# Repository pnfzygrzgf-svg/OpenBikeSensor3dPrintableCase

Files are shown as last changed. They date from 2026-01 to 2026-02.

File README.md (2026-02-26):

# OpenBikeSensor Case

This repository contains the 3d-printable models for OpenBikeSensor enclosures.

[Project Website](https://openbikesensor.org) |
[Model selection](https://www.openbikesensor.org/device/) (German) |
[3D printing instructions](https://www.openbikesensor.org/docs/hardware/general/case/) (German)

> **Fork notice:** This repository is a **fork/clone** of the official
> [OpenBikeSensor case repository](https://github.com/openbikesensor/OpenBikeSensor3dPrintableCase)
> and includes additional variants.
>
> **New in this fork:**
> - **OpenBikeSensor Lite LiDAR case** (`src/LiteCaseLidar`) — enclosure for OBS Lite using a TF-Luna LiDAR sensor instead of ultrasonic
> - **18650 Battery Shield V3 cases** — enclosures for the battery shield, with variants for standard mount and LiDAR lid
> - **Extended seat post mount** (`SeatPostMount_long`) — longer seat post mount for more clearance
> - **Improved DisplayCase parametrization** — better OpenSCAD Customizer support

If you encounter any problems or have feature requests, please open an issue on
GitHub. If you need assistance related to the contents of this repository,
please ask in the [project forums](https://forum.openbikesensor.org).

## Cloning
If you want to build your own case using openscad instead of using the
readymade exports or if you want to start the customizer be aware
that you need to clone including git submodules:

```
git clone --recursive https://github.com/openbikesensor/OpenBikeSensor3DPrintableCase
# ... or if you forgot the --recursive argument, you can run this in the
# repository's directory later:
git submodule update --init --recursive
```

## About the files

We expect a recent version of OpenSCAD, for development we currently use OpenSCAD 2021.

This repository contains a lot of files for different options

* The `export/` folder contains the latest prebuilt `.stl` files for 3D printing.
  You can use those unless you want to make customizations. If you contribute
  changes to the models, you can refresh the models you changed using the
  ``make export-all`` command. If your ``openscad`` binary does not reside
  in ``/usr/bin/openscad`` you can specify its location by overriding the
  ``OPENSCAD`` variable like so (substitute your specific openscad path): ``make -j OPENSCAD=/Applications/OpenSCAD.app/Contents/MacOS/OpenSCAD``
* The `legacy/` folder contains old versions of the case, including lots of
  variants that were created but unmaintained. These were built with
  proprietary software packages and often available in their native format(s)
  and therefore mostly uneditable for most of the community. A lot of these
  files are also available in STEP format, and of course exported as STL for
  printing. We keep these files around for reference and convenience.
* The `lib/` folder contains common OpenSCAD files with library functions and
  modules, as well as exports of other objects that can be imported in the part
  files, e.g. to check dimensions.
* The `src/` folder contains OpenSCAD scripts for all parts. Not all parts are
  needed for printing a working enclosure. Please check the documentation
  (links on top) to assemble your custom list of parts for the variant you want
  to build.
* The `render/thumbnails/` folder contains rendered views of the parts. These images
  should be refreshed with changes to the parts using the `make thumbnails`
  command if you plan to submit your changes. They are used in this `README.md`.
* The `variables.scad` file contains all variables used in any of the parts.
  You can customize everything by editing this file, or passing new variable
  values on the OpenSCAD command line.

## The Standard Variant

There is a notion in the OpenBikeSensor community to label one combination of
parts and a certain version of the electronics the "Standard Model" (read about
it [here](https://www.openbikesensor.org/docs/hardware/general/models/)). This
is meant to get you started, without having to check for compatibility and
without cross referencing multiple parts of the documentation to build your own
version of the device.

> **Warning**
> We only keep the rail shapes constant between versions. When printing make sure that your ``MainCase`` and ``MainCaseLid`` come from the same release. The same is true for ``DisplayCase`` Top and Bottom. The Idea is that OpenBikeSensors can be mounted on a different bike with older version mounts, but the current version lid won't necessarily fit onto last years case.

To get a standard variant, print these parts:

```
MainCase/GpsAntennaLid
MainCase/MainCase
MainCase/UsbCover
MainCase/MainCaseLid
DisplayCase/DisplayCableStrainRelief (2x)
DisplayCase/DisplayCaseBottom
DisplayCase/DisplayCaseTop
Mounting/StandardMountAdapter
Mounting/SeatPostMount
Mounting/LockingPin
Mounting/HandlebarRail
```

## Compatibility

The parts are compatible with the OpenBikeSensor PCB Version `00.03.12`. Other
versions, both older and newer, might work, but are untested.

## Part list

This is a list of all available parts, and a description of what they are used for.

### Main case

The main case of the device enclosure. This will contain most of the
electronics. The core part are a `MainCase` and a `MainCaseLid`, which is
installed with five M3x8 bolts in the lid, matching the five threaded heatset
inserts in the body.

The PCB is installed into the main body with 3 heat-set inserts and M3x8 bolts.
One additional heat-set insert is required for the `GPSAntennaLid` (see below).
This totals 9 inserts to be placed after printing.

MainCase/MainCase

MainCase/MainCaseLid

#### GPS antenna lid

The `GpsAntennaLid` covers the part of the main enclosure with the GPS antenna.
It is held in place by only one M3x8 bolt and can be removed to reveal the
antenna, behind which there is an access hole for the Micro-USB receptable of
the ESP32 dev board -- very useful for debugging or developing the firmware.

MainCase/GpsAntennaLid

#### USB-C port cover

The `UsbCover` is small plug for the USB-C port on the bottom of the device,
which is used for charging the battery. This plug is held in place by 2 pairs
of 3x3x3mm neodymium magnets.

MainCase/UsbCover

### Display case

The display case consists of two halfs, `DisplayCaseTop` and
`DisplayCaseBottom`. The display case contains the I2C display and a push
button and is attached to the main device with a cable that exits through a
hole in the bottom part.

The bottom part contains 3 threaded heat-set inserts and a pocket for two
20x10x1.9mm neodymium magnets. The magnets hold the display in the rail on the
handlebar (see `HandlebarRail`).

DisplayCase/DisplayCaseTop

DisplayCase/DisplayCaseBottom

#### Display cable strain relief

*Print two copies of this.*

The `DisplayCableStrainRelief` holds the display cable firmly in place inside
the display case to prevent strain on the solder joints or crimped connectors
inside. The two halves are pushed into the hole at an angle one after the
other, and then screwed together with two M3x8 bolts and hex nuts.

DisplayCase/DisplayCableStrainRelief

### Mounting

#### Standard mount adapter

The `StandardMountAdapter` is screwed onto the main enclosure. It contains a
channel for the display cable to sit in, pressing it firmly against the outer
wall of the main case and relieving any strain from its connector inside.

This adapter is used to attach the device to the mount that is permanently
affixed to the bike. There may be different adapters in the future for
different attachment needs, but this one is the default.

Mounting/StandardMountAdapter

#### Seat post mount

The `SeatPostMount` gets attached to the seat post of the bicycle with zip ties.

*Hint: A piece of an old bicycle tube can prevent it from turning or shifting.*

This is a counterpart to the `StandardMountAdapter`, which can slide onto this
part's rail and be held in place with a `LockingPin`.

Mounting/SeatPostMount

#### Top tube mount

The `TopTubeMount` gets attached to the top tube of the bicycle frame, similar
to the seat post mount.

*Hint: A piece of an old bicycle tube can prevent it from turning or shifting.*

This is also compatible with the `StandardMountAdapter` and `LockingPin`. Make
sure to use a "Top Rider" variant main case (see below for details).

Mounting/TopTubeMount

#### Locking pin

Screw an M3x16 to M3x20 bolt through the `LockingPin` part, such that the
bolt's head sits on the long handle's side. Now you have a pin that you can
push into the hole in the `StandardMountAdapter` and turn 180 degrees, holding
the pin, and the device, in place.

Mounting/LockingPin

#### Handlebar rail

Attach the `HandlebarRail` to the handlebar of your bike with two zip ties or a single
hose clamp. Again, a piece from an old bicycle tube can prevent turning and shifting.

The large wall contains a pocket for two 20x10x1.9mm neodymium magnets, pushed
in one after the other. Make sure to consider their polarity to match those of
the display. The display can now slide onto this rail and is held in place by
the magnets.

Mounting/HandlebarRail

An alternative Handlebar rail can be mounted like most bike computers with a
rubber o ring;
Mounting/HandlebarRailOring

Often you find magnets where one magnet is strong enough for your display - you
can use a platic decoy to save on magnets in these cases
Mounting/DisplayMagnetDummy

#### Bike rack mount

The bike rack mount can be used to attach a "Top Rider" main case to a standard
bicycle rack. It consists of two parts, the `BikeRackMountSide` (which is
required twice) and `BikeRackMountCenter` or `BikeRackMountCenterLongitudinal`.

The side parts are mounted on the longitudinal rails of the rack, either above
or hanging below. They are connected with two rods (aluminium or wood) that
form cross beams, cut to sized depending on the width of the bike rack. In the
center of these rods sits the center piece, which has the attachment rail for
the sensor.

In a rotated version, the rods are aligned longitudinally, a difference center
piece (`BikeRackMountCenterLongitudinal`, third image) is used to rotate the
OBS correctly. Use this if you need your bike rack's longitudinal tubes for
attaching cargo, and you want to mount the OBS on the cross beams of the rack.

The rods can be affixed to the 3D printed parts by gluing them in place, once
they have been sized and fitted to your rack.

Mounting/BikeRackMountSide

Mounting/BikeRackMountCenter

Mounting/BikeRackMountCenterLongitudinal

#### Attachment cover

If you have a main case that has both attachment points (top rider and back
rider), you may want to cover the one of them that you are not using, such that
the screw holes and (optional) cable hole are not left open. The
`AttachmentCover` is a simple cover that fits the screw pattern.

Mounting/BikeRackMountSide

#### Back rider to top rider adapter

This adapter allows the use of a "back rider" main case on a "top rider" mount.
Print a second locking pin as well.

Mounting/BackRiderTopRiderAdapter

## Customization

There are tons of variables in the `variables.scad` file, mostly dimensions,
which can be adjusted to suit your needs. Some of these variables are however
not necessarily wise to be changed, as other dimensions might inadvertently
depend on them, or they might produce invalid results in certain ranges.

However, some options are meant to be changed to suit your specific needs. The
defaults get you most of the way, but certainly, some users will need a
different set of features, so here is a list of options you might want to
change:

### Print settings

Some options exist to control sizes and features that have been added just for
3D printing ease. Configure these to match your printing setup. The defaults
should work for most printers, but if you modify your settings greatly (e. g.
to print faster), you might also need to change these model parameters:

```
extrude_width
enable_easy_print
layer_height
default_clearance
```

### Top Rider vs. Back Rider

A "top rider" variant main case has an attachment port on the bottom (when
mounted), while a "back rider" has it on the front. The "traditional" OBS case
therefore is a back rider variant, as it used to always sit behind the seat
post, attached horizontally. However, many cyclists configure their bikes in a
way that there is not enough room for a whole OBS below the seat, so a
different way of attaching the OBS is needed.

Top riders can sit on the top tube, the luggage rack, or anywhere else where
there is support from below. Moving the attachment point on the main case makes
it simple to design compatible mounts with their rail on top, without a
complicated structure that "goes up and around" to provide a backwards-facing
rail.

A single case can have both top rider and back rider attachment ports. They
don't necessarily need to have an adapter attached, though it is recommended to
do so in order to fill the screw and cable holes.

To configure whether to generate top and/or back riders, set the following
variables. The `_cable` variables control whether the corresponding attachment
port (if it exists) has a hole for the cable or not.

```
MainCase_back_rider
MainCase_top_rider
MainCase_back_rider_cable
MainCase_top_rider_cable
```

The `Mounting/BackRiderTopRiderAdapter` is available for people who have a back
rider and would like to use a top rider mount. The opposite is not available.

### Dimensions

* General
  * `m3_screw_diameter_loose`: A hole for an M3 bolt has this diameter. The
    bolt is not meant to grab this hole, but slide into and out of it ("loose"
    fit). For (almost) each bolt, there is a corresponding threaded metal part
    (nut or insert), so increase this value if your bolts are hard to get where
    they need to go. Print `Calibration/ScrewHoles` to find a good value for
    your printer.
  * `m3_hex_nut_diameter`: The outer circle around a hex nut's hexagon has this
    diameter. This is **not** the same as the "wrench size" from [DIN
    934](https://www.fasteners.eu/standards/DIN/934/) (dimension `S`), but its
    nominal value is `2 / sqrt(3) * S`. For M3, this equals `6.35mm` nominally.
    Increase this for more clearance. Print `Calibration/HexNuts.stl` to find a
    good value for your printer.
* `SeatPostMount`
  * `SeatPostMount_angle`: Set to the angle that your seat post is away from
    the vertical in degrees (usually around 20). This ensures that the device
    will sit horizontally behind the seat post.
  * `SeatPostMount_diameter`: Set to the diameter of your seat post (in mm).
    The default for most bicycles today is 28.
  * `SeatPostMount_length`: Increase this to lengthen the mount,
    shifting the device further backwards on your bike. You might consider
    angular force, so don't set it too high, but this can help if your mount is
    hard to reach, or if the device disappears underneath your seat,
    potentially blocking GPS signal.
* `HandlebarRail`
  * `HandlebarRail_tube_radius`: The radius (half diameter) of your handlebar,
    in mm.

### Logo customization

The `Makefile` supports generating the case with different logos. For now, the
only parts that are customizable with logos are `MainCase/MainCase` and
`MainCase/MainCaseLid`. Please check the instructions in
[`logo/README.md`](./logo/README.md) for creating your own logo version.

## Legacy parts

The files of legacy versions are available in the ``.stl`` format for 3D
printing. But these are discretized versions of more universal 3D Geometry that
can be read and edited by CAD software.

This is a grown project and in the past contributions have been made with
different CAD Programs. Some parts were designed/modified in Autodesk inventor
(filenames `*.ipt`), some were designed in Fusion360 (filenames `*.f3d`), but
for most parts a step file (`*.stp, *.step`) is available which can be opened
by most CAD Programs. For your contributions in CAD software of your choice it
would be great if you could also follow the practice of submitting your changes
in both `.stl` for 3D-Printing and `.step` for later editing - and maybe the
native format of your CAD software on top.

OpenSCAD is a special case of course: Here submitting `.stl` (for now) and the
`.scad` file is sufficient. 

### Customizer webservice

To run the customizer webservice you run it from the dockerfile (and be sure
that you cloned the repo recursively before building the cointainer:

```
git submodule update --init --recursive
docker build . -t customizer
docker run --rm -p 8001:80 customizer 
```

Whereafter you should be able to access your customizer on your host on port 8001.

Alternatively you can launch the python module directly using uvicorn,
but that is only recommended for dev setups an d will be described
in the module readme.

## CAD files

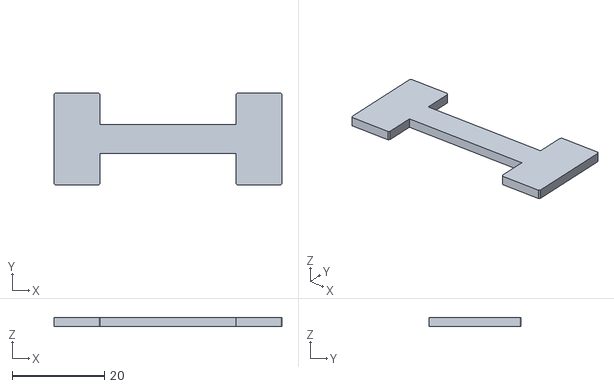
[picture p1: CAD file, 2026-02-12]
src/LiteCaseLidar/Spacer.stl
49.5 x 20.0 x 2.00

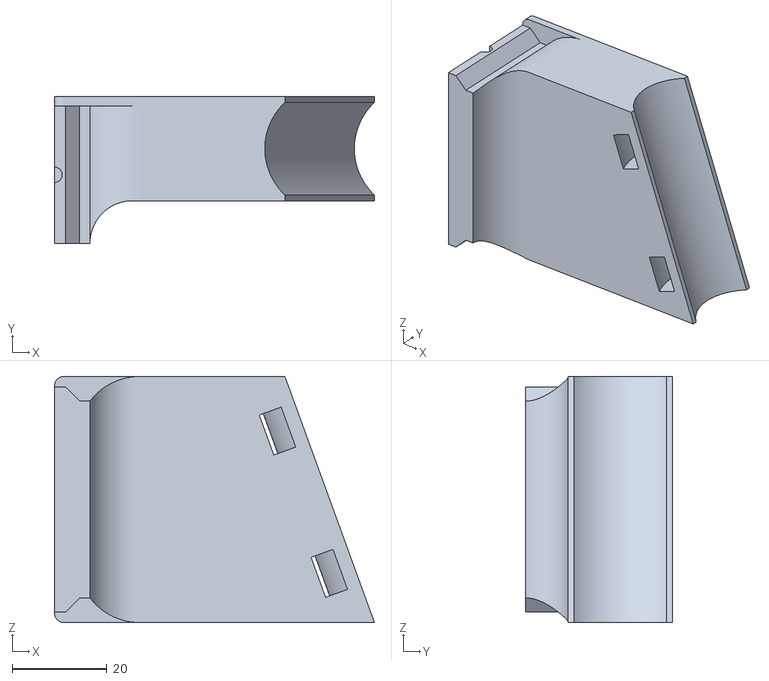
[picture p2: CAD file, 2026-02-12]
src/LiteCaseLidar/SeatPostMount_long.stl
67.6 x 31.0 x 52.0

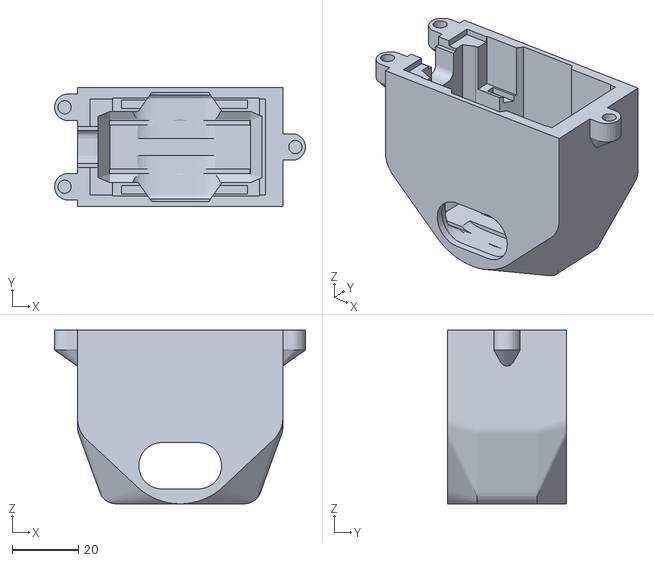
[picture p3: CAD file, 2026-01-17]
src/LiteCaseLidar/LiteCase_lidar_Schale.stl
75.8 x 36.0 x 52.4

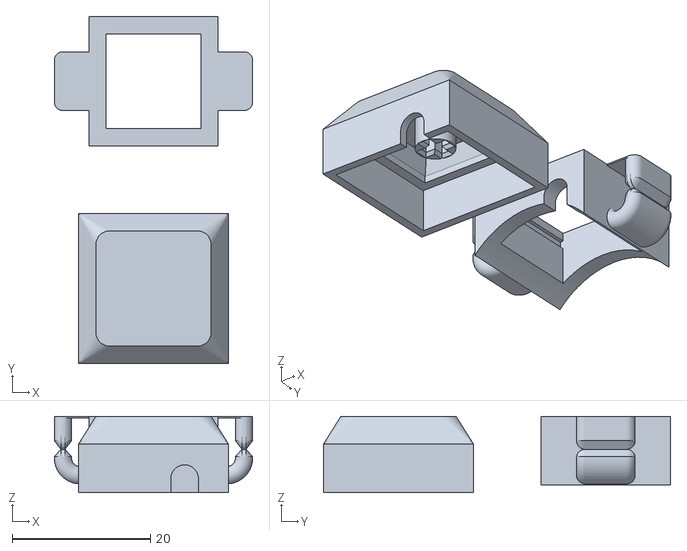
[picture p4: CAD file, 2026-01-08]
src/LiteCaseLidar/HandlebarButton.stl
28.7 x 50.2 x 11.0

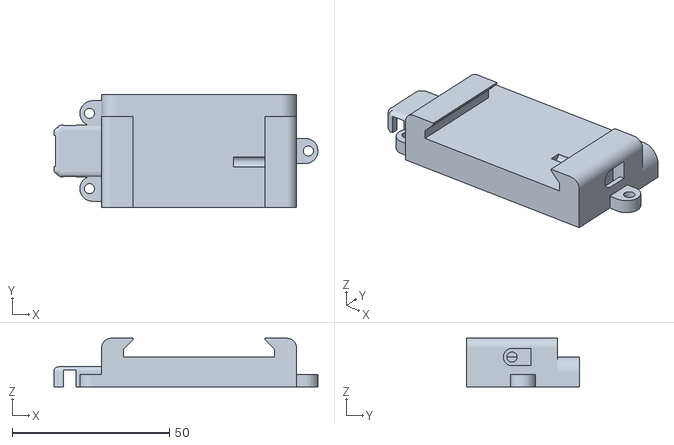
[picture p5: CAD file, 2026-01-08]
src/LiteCaseLidar/LiteCase_lidar_Deckel.stl
84.0 x 36.0 x 15.5

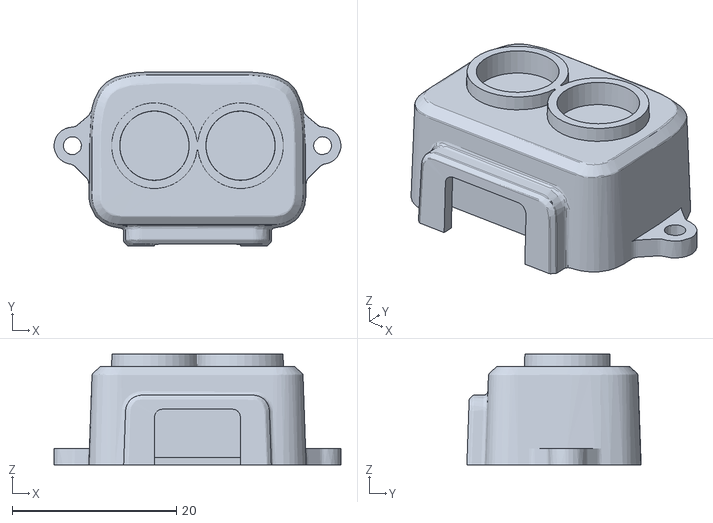
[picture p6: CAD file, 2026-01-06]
src/LiteCaseLidar/tfluna.stl
35.0 x 21.2 x 13.5

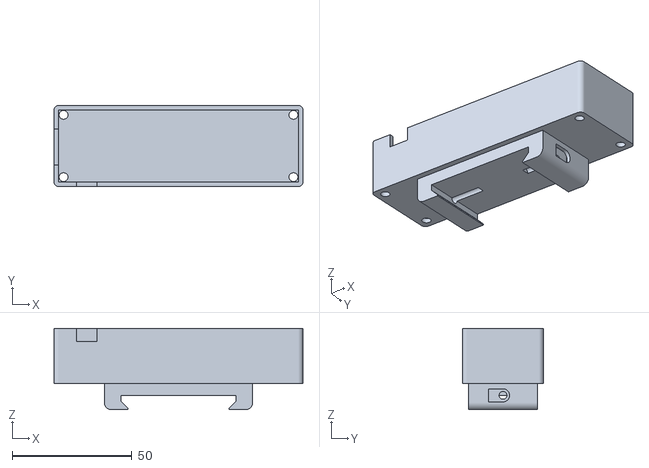
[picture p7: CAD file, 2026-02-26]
src/LiteCaseLidar/18650_BatteryShield_with_StandardMount.stl
104.0 x 34.0 x 34.0

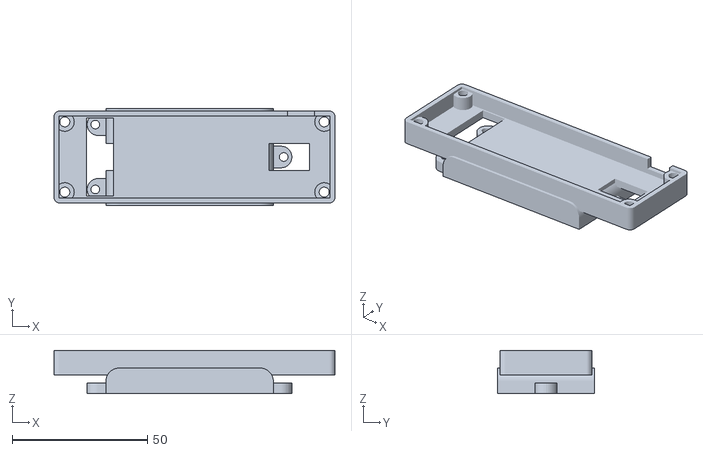
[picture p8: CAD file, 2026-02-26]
src/LiteCaseLidar/18650_BatteryShield_with_LiteCase_lidar_Deckel.stl
104.0 x 36.0 x 16.0

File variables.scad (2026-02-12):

// ==========================================================
//                      GLOBAL SETTINGS
// ==========================================================

// --------------
// Print settings
// --------------

// In some places we need to ensure a minimum wall thickness, so set this to
// your extrusion width. The default of 0.46mm is the PrusaSlicer default for a
// 0.4mm nozzle.
extrude_width = 0.46;

// Simplifies printing by adding smart bridges to remove need for supports.
enable_easy_print = true;
enable_text = true;
fix_svg = false;

// Used e.g. by easy print algorithms.
layer_height = 0.2;

// Size of the gap between two things that should fit into each other. This is
// gap size, so it applies to radii, not diameters.
default_clearance = 0.2;

// Set to false to generate nice previews and such, to true for printing output
// in proposed orientation.
orient_for_printing = false;

// ----------------------
// Model quality settings
// ----------------------

fast = $preview; // in fast mode, not all features are rendered
$fs = 0.2;
$fa = 1;
$fn = fast ? 24 : 120;
$pfn = $fn; // for polyRound
epsilon = 0.01; // infinitesimal thickness for slabs in hull - can be increased to see if offsets were done right.


// ==========================================================
//                    CUSTOMIZABLE OPTIONS
// ==========================================================

// A "back rider" is a case that has the attachment on front, riding e. g.
// behind the seat post. A "top rider" is a case that has an attachment on its
// bottom, sitting on top of a compatible mount, such as on the top tube or
// luggage rack. A single MainCase can be both back rider and top rider.
MainCase_back_rider = true;
MainCase_top_rider = true;
MainCase_back_rider_cable = true;
MainCase_top_rider_cable = true;

// General thickness of all walls of the main case and where applicable
wall_thickness = 2;

// -------------------------
// Dimensions of M3 hardware
// -------------------------

m3_screw_diameter_tight = 3.0; // screw should grab the plastic well
m3_screw_diameter_loose = 3.25; // screw should slide in nicely
m3_screw_head_depth = 3; // minimum depth for sinking the screw head
m3_screw_head_diameter = 6; // can have a little clearance
m3_hex_nut_diameter = 6.45; // outer circle, *not* wrench size (S), but `S*2/sqrt(3)`, plus clearance
m3_hex_nut_thickness = 2.5; // found different nut specifications, 2.5 is the maximum thickness I found named
m3_insert_hole_diameter = 4;
m3_insert_hole_depth = 6.0 ;
m3_insert_cavity_depth = 6.0 - 4.5;  // size of cavity on the bottom for displaced plastic
m3_insert_cavity_diameter = m3_insert_hole_diameter + 1;


// ==========================================================
//                     PART DIMENSIONS
// ==========================================================

// Warning: It may not be safe to modify all variables in this section, as they
// may not be tested for all desirable ranges and produce non-working results.
// Use at your own risk.

UsbCover_height = 9.7;
UsbCover_foot_height = 1.5;
UsbCover_width = 15.5;
UsbCover_depth = 6.5;
UsbCover_foot_length = 2.5;
UsbCover_r1 = 1.8; // the rounded corners with smaller radius
UsbCover_r2 = 2; // the rounded corners with bigger radius
UsbCover_magnet_size = 3.0; // decrease if magnets are too loose
UsbCover_magnet_clearance = 0.25; // increase if your printer needs more clearance for press fit
UsbCover_magnet_depth = 3.2;
UsbCover_magnet_spacing = 6.5; // center to center
UsbCover_indent_depth = 1.5;
UsbCover_indent_height = 4;
UsbCover_indent_width = 12;
UsbCover_wing_offset = 2.2;
UsbCover_wing_width = 2.6;
UsbCover_wing_length = 2.0;
UsbCover_clearance_correction = default_clearance; // printing a smaller-than-spec part for main cases that have not enough clearance themselves

MainCase_small_corner_radius = 5;
MainCase_switch_offset_x = 25;
MainCase_sensor_hole_diameter = 22.3; // 0.3 clearance
MainCase_sensor_hole_ledge = 1.0;

MainCase_pcb_offset = [1, UsbCover_depth + 0.5];
MainCase_pcb_holes = [[3.29+1.5, 23.75], [8.89+1.5, 49.3], [60.8+1.5, 41.63], [3.85+1.5, 61.65]];
// MainCase_pcb_dimensions = [64.64, 68.17, 2];

// found through experimentation
MainCase_usb_port_x_offset = 19.7+wall_thickness;
MainCase_usb_port_vertical_offset = 3.13; // center below the board bottom
MainCase_usb_port_housing_height = 14;
MainCase_usb_port_housing_width = 32;
MainCase_usb_port_housing_depth = MainCase_pcb_offset.y;
MainCase_usb_port_cover_clearance = default_clearance;

OBS_height = 72;
OBS_width = 113;
OBS_width_small = 88;
OBS_depth = 48;

MainCase_gps_antenna_y_offset = 32;
MainCase_gps_antenna_housing_hole_width = 26;
MainCase_gps_antenna_housing_hole_height = MainCase_gps_antenna_housing_hole_width;

MainCase_gps_antenna_lid_thickness = 2;
MainCase_gps_antenna_lid_offset = 3;
MainCase_gps_antenna_lid_tab_width = 10;
MainCase_gps_antenna_lid_tab_depth = 2;
MainCase_gps_antenna_lid_tab_height = 1;

MainCase_gps_antenna_height = 9;
MainCase_gps_antenna_housing_depth = MainCase_gps_antenna_height+MainCase_gps_antenna_lid_thickness;
MainCase_gps_antenna_housing_top_width = MainCase_gps_antenna_housing_hole_width-1;
MainCase_gps_antenna_housing_top_height = MainCase_gps_antenna_housing_hole_height+12;
MainCase_gps_antenna_housing_top_radius = 2;
MainCase_gps_antenna_housing_bottom_offset = 2;
MainCase_gps_antenna_housing_bottom_width = MainCase_gps_antenna_housing_top_width + 2 * MainCase_gps_antenna_height;
MainCase_gps_antenna_housing_bottom_height = MainCase_gps_antenna_housing_top_height + 2 * MainCase_gps_antenna_height - MainCase_gps_antenna_housing_bottom_offset;
MainCase_gps_antenna_housing_bottom_radius = MainCase_gps_antenna_housing_top_radius + MainCase_gps_antenna_housing_depth;
MainCase_gps_antenna_housing_screw_offset = 3;
MainCase_gps_antenna_housing_cable_hole_diameter = 6;

MainCase_micro_usb_offset = 30 + MainCase_pcb_offset.y + wall_thickness;
MainCase_micro_usb_width = 16;
MainCase_micro_usb_height = 14;
MainCase_micro_usb_chamfer = 4;

frontside_angle = atan((OBS_width - OBS_width_small) / OBS_height);

MainCaseLid_rim_clearance = 0.3;
MainCaseLid_rim_thickness = 3.0;
MainCaseLid_rim_width = 1;
MainCaseLid_rim_radius = 12;
MainCaseLid_thickness = 2.1;

MainCaseLid_hole4_offset_x = 35;
MainCaseLid_hole_offset = 3.5; // distance from inner wall
MainCaseLid_hole_positions = [
  [MainCaseLid_hole_offset+wall_thickness, MainCaseLid_hole_offset+wall_thickness],
  [OBS_height-MainCaseLid_hole_offset-wall_thickness, MainCaseLid_hole_offset+wall_thickness],
  [MainCaseLid_hole_offset+wall_thickness, OBS_width_small-MainCaseLid_hole_offset-wall_thickness-5],
  [OBS_height-MainCaseLid_hole_offset-wall_thickness, OBS_width_small-MainCaseLid_hole_offset-wall_thickness-5],
  [OBS_height-MainCaseLid_hole4_offset_x+4.5*cos(frontside_angle), OBS_width-tan(frontside_angle)*MainCaseLid_hole4_offset_x-3.5],
];

MainCaseLid_battery_holder_lift = 1.5;
MainCaseLid_battery_holder_inner_radius = 8;
MainCaseLid_battery_holder_inner_width = 18.3;
MainCaseLid_battery_holder_height = 11.5;
MainCaseLid_battery_holder_length = 37.6;

MainCaseLid_battery_holder_channel_depth = 2;
MainCaseLid_battery_holder_channel_radius = 5;
MainCaseLid_battery_holder_channel_extra_length = 5;
MainCaseLid_battery_holder_channel_width = 5;
MainCaseLid_battery_holder_channel_spacing = 17.6 + 5;

MountRail_base_width = 48;
MountRail_base_height = 2.5;
MountRail_chamfer_height = 3;
MountRail_plate_width = MountRail_base_width - 2 * MountRail_chamfer_height;
MountRail_plate_distance = 2;
MountRail_total_height = MountRail_base_height + MountRail_chamfer_height + MountRail_plate_distance;
MountRail_clearance = 0.2;
MountRail_width = 29.0;
MountRail_pin_length = 15;

SeatPostMount_width = 22; // [18:25]
SeatPostMount_angle = 20; // [0:35]
SeatPostMount_diameter = 28; // [18:36]
SeatPostMount_stop_plate_thickness = 2; // [1:0.1:3]
SeatPostMount_stop_plate_width = MountRail_base_width  + 4;
SeatPostMount_length = 20; // [15:100]
SeatPostMount_long_length = 60; // 
SeatPostMount_channel_depth = 4; // [1:20]

// TODO: decide on a namespace, at least `*_holes_dx/dy` are global
MountAttachment_depth = 4;
MountAttachment_height = 47;
MountAttachment_width = 27;
MountAttachment_holes_x_offset = -0.5;
MountAttachment_holes_dx = 15;
MountAttachment_holes_dy = 33;

DisplayCase_outer_radius = 5;
DisplayCase_outer_width = 30;
DisplayCase_outer_large_radius = 12;
DisplayCase_magnet_length = 20;
DisplayCase_magnet_thickness = 2;
DisplayCase_magnet_housing_width = 2*DisplayCase_magnet_thickness+default_clearance+2*extrude_width;
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

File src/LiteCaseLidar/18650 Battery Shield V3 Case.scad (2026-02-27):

// SPDX-License-Identifier: LGPL-3.0-or-later
// SPDX-FileCopyrightText: OpenBikeSensor contributors

//18650 Battery Shield V3 Case

// Welches Teil soll gerendert werden?
part = "both"; // Optionen: "top", "bottom", "both"

$fn=50;

// Radius für Kantenrundung
kantenradius = 2;

// PETG Drucktoleranz
toleranz = 0.1;

// V3 Dimensionen
length = 100;
width = 30;
holelength = 2;
holewidth = 2;

// Abstand zwischen den Teilen wenn beide angezeigt werden
spacing = 10;

if (part == "top" || part == "both") {
    topcase();
}

if (part == "bottom") {
    bottomcase();
}

if (part == "both") {
    translate([0, width + spacing, 0])
        bottomcase();
}

module topcase() {
    difference() {
        
        minkowski() {
            translate([-2 + kantenradius, -2 + kantenradius, -2]) 
                cube([length + 4 - 2*kantenradius, width + 4 - 2*kantenradius, 23 - kantenradius]);
            cylinder(r=kantenradius, h=kantenradius);
        }
        
        translate([-toleranz, -toleranz, 0])
            cube([length + 2*toleranz, width + 2*toleranz, 24]);
        
        translate([5.5 - toleranz, 2 - toleranz, 0])
            cube([length - 10.5 + 2*toleranz, width - 4 + 2*toleranz, 26]);
        
        // USB-Port V3
        translate([-4, 7, 13]) cube([10, 15, 8]);
        
        // Power Button
        translate([7.5, -2, 15.5]) cube([8.5, 5, 5.5]);
        
        // Nur Schaftbohrungen, Kopf liegt auf
        translate([holelength, holewidth, -4])               cylinder(30, 3.5/2 + toleranz, 3.5/2 + toleranz);
        translate([holelength, width-holewidth, -4])         cylinder(30, 3.5/2 + toleranz, 3.5/2 + toleranz);
        translate([length-holelength, holewidth, -4])        cylinder(30, 3.5/2 + toleranz, 3.5/2 + toleranz);
        translate([length-holelength, width-holewidth, -4])  cylinder(30, 3.5/2 + toleranz, 3.5/2 + toleranz);
    }
}

module bottomcase() {
    difference() {
        union() {
            difference() {
                // Abgerundeter Aussenkörper – Boden 3mm (z=-3)
                minkowski() {
                    translate([-2 + kantenradius, -2 + kantenradius, -3]) 
                        cube([length + 4 - 2*kantenradius, width + 4 - 2*kantenradius, 9 - kantenradius]);
                    cylinder(r=kantenradius, h=kantenradius);
                }
                
                // Innenraum
                translate([-toleranz, -toleranz, 0])
                    cube([length + 2*toleranz, width + 2*toleranz, 10]);
                
                // USB-Port
                translate([length-15.5, width-2, 2]) cube([10, 5, 6]);
                
                // Zusätzliches Loch 1
                loch_rotation = 90;
                loch_links_rechts = -30;
                loch_hoch_runter = 0;
                loch_z = -27;
                
                translate([length/2 + loch_links_rechts, width/2 + loch_hoch_runter, 19 + loch_z]) 
                    rotate([0, 0, loch_rotation]) 
                    translate([-29/2, -0, 0]) 
                    cube([29, 10, 10]);
                
                // Zusätzliches Loch 2
                loch2_breite = 10;
                loch2_tiefe = 15;
                loch2_rotation = 90;
                loch2_links_rechts = 35;
                loch2_hoch_runter = 0;
                loch2_z = -27;
                
                translate([length/2 + loch2_links_rechts, width/2 + loch2_hoch_runter, 19 + loch2_z]) 
                    rotate([0, 0, loch2_rotation]) 
                    translate([-loch2_breite/2, -loch2_tiefe/2, 0]) 
                    cube([loch2_breite, loch2_tiefe, 10]);
            }
            
            // Schraubenhalterung V3 – Zylinder
            translate([holelength, holewidth, 0])              cylinder(h=5, r=3.5);
            translate([holelength, width-holewidth, 0])        cylinder(h=5, r=3.5);
            translate([length-holelength, holewidth, 0])       cylinder(h=5, r=3.5);
            translate([length-holelength, width-holewidth, 0]) cylinder(h=5, r=3.5);
        }
        
        // Schraubenlöcher V3
        translate([holelength, holewidth, 0])              cylinder(6, 3.5/2 + toleranz, 3.5/2 + toleranz);
        translate([holelength, width-holewidth, 0])        cylinder(6, 3.5/2 + toleranz, 3.5/2 + toleranz);
        translate([length-holelength, holewidth, 0])       cylinder(6, 3.5/2 + toleranz, 3.5/2 + toleranz);
        translate([length-holelength, width-holewidth, 0]) cylinder(6, 3.5/2 + toleranz, 3.5/2 + toleranz);
        
        // Mutterneinsatz M3 SW5.5, Tiefe 3mm
        translate([holelength, holewidth, -3])              rotate(90) cylinder(3, 5.5/2 + toleranz, 5.5/2 + toleranz, $fn=6);
        translate([holelength, width-holewidth, -3])        rotate(90) cylinder(3, 5.5/2 + toleranz, 5.5/2 + toleranz, $fn=6);
        translate([length-holelength, holewidth, -3])       rotate(90) cylinder(3, 5.5/2 + toleranz, 5.5/2 + toleranz, $fn=6);
        translate([length-holelength, width-holewidth, -3]) rotate(90) cylinder(3, 5.5/2 + toleranz, 5.5/2 + toleranz, $fn=6);
    }
}

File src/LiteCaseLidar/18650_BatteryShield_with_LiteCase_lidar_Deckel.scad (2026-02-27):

// SPDX-License-Identifier: LGPL-3.0-or-later
// SPDX-FileCopyrightText: OpenBikeSensor contributors

// ============================================================
// LiteCaseLidar Deckel + 18650 Battery Shield V3 Bottom
// ============================================================
use <../../lib/Round-Anything/polyround.scad>
// ============================================================
// CONFIG
// ============================================================
$fn = 40;
// Welches Teil rendern?
render_part = "combined";  
// Optionen:
// "litecaselidar_bottom" = nur LiteCaseLidar Unterteil
// "battery_bottom" = nur Battery Shield Unterteil
// "combined" = LiteCaseLidar mit Battery Shield oben drauf
// "both" = beide nebeneinander
// "preview" = LiteElectronics Preview
// Battery Shield Position auf LiteCaseLidar (nur für "combined")
battery_offset_x = -42;      // X-Verschiebung
battery_offset_y = -15;      // Y-Verschiebung  
battery_offset_z = 10;     // Z-Verschiebung (Höhe über LiteCaseLidar)
battery_rotation_x = 0;    // Rotation um X-Achse in Grad
battery_rotation_y = 0;    // Rotation um Y-Achse in Grad
battery_rotation_z = 0;    // Rotation um Z-Achse in Grad
// Abstand zwischen Teilen wenn "both"
parts_spacing = 120;
// ============================================================
// TF-LUNA CONFIG
// ============================================================
tfluna_file             = "tfluna.stl";
tfluna_scale            = [1, 1, 1];
tfluna_rot_common       = [90, 0, -180];
tfluna_mirror_axis      = [0, 0, 1];
tfluna_pos_offset_m     = [0,  2, 15];
tfluna_pos_offset_p     = [0, -2, 15];
tfluna_cutter_scale_up  = 1.1;
show_tfluna_preview     = true;
tfluna_preview_alpha    = 0.55;
tfluna_preview_color    = "orange";
// ============================================================
// THROUGH-BOHRUNGEN (OVAL) CONFIG
// ============================================================
through_enable          = true;
through_preview         = true;
through_base_pos        = [23.8, 0, 20.6];
through_offset          = [0, 0, 5];
through_oval_length     = 25;
through_d               = 14;
through_sep_vec         = [1, 0, 0];
through_clearance       = 0.0;
through_axis            = "y";
through_h               = 50;
// ============================================================
// LITECASELIDAR PARAMETERS
// ============================================================
corner_x = 24;
boardcorner_x = 17;
boardcorner_y = 23;
square_x = 5;
lite_l = 45;
lite_w = 80 - 18;
Lite_PCB_Dimensions = [44, 29.2, 1.7];
Lite_ESP_socket_dimensions = [38, 2.54, 9 + Lite_PCB_Dimensions[2] + 1.8];
Lite_transducer_position       = [23.8, 0, 20.6];
Lite_transducer_variance       = 1.2;
Lite_transducer_diameter       = 16 + Lite_transducer_variance;
Lite_transducer_diameter_small = 12.5 + Lite_transducer_variance;
Lite_ESP_position   = [0, 0, -16.2];
Lite_ESP_dimensions = [53, 29, 4.8];
Lite_USB = [55, 0, -14.5];
Lite_screwmount_top    = 4;
Lite_screwmount_bottom = 6;
Lite_screwmount_height = Lite_screwmount_top + Lite_screwmount_bottom;
sensor_x = -Lite_transducer_position[2] + 0.5;
sensor_y =  Lite_transducer_position[0];
// ============================================================
// BATTERY SHIELD V3 PARAMETERS
// ============================================================
kantenradius = 2;
toleranz = 0.1;
length = 100;
width = 30;
holelength = 2;
holewidth = 2;
// ============================================================
// HELPERS
// ============================================================
function angle_three_points_2d(pa, pb, pc) =
  asin(cross(pb - pa, pb - pc) / (norm(pb - pa) * norm(pb - pc)));
module rounded_cube(x, y, z, r, r2, center = true) {
  t = center ? -[x/2, y/2, z/2] : [0, 0, 0];
  translate(t)
    polyRoundExtrude(
      [[0,0,max(r,r2)], [0,y,max(r,r2)], [x,y,max(r,r2)], [x,0,max(r,r2)]],
      z, r, r2
    );
}
// ============================================================
// LITECASELIDAR SHELL GEOMETRY
// ============================================================
module SidePolygon() {
  corners = [
    [square_x,  -lite_w/2, 9],
    [-corner_x, -0,
      (corner_x - boardcorner_x) /
      (1 / sin(angle_three_points_2d([0,0], [-corner_x,-0], [square_x, lite_w/2])) - 1)
    ],
    [square_x,   lite_w/2, 9],
    [lite_l,     lite_w/2, 5],
    [lite_l,    -lite_w/2, 5]
  ];
  translate([sensor_x, sensor_y]) polygon(polyRound(corners, fn = 150));
}
module MidPolygon() {
  corners = [
    [square_x,       -lite_w/2, 5],
    [-boardcorner_x, -boardcorner_y, 5],
    [-boardcorner_x,  boardcorner_y, 5],
    [square_x,        lite_w/2, 5],
    [lite_l,          lite_w/2, 5],
    [lite_l,         -lite_w/2, 5]
  ];
  translate([sensor_x, sensor_y]) polygon(polyRound(corners));
}
module LidCutter() {
  translate([40, 0, Lite_ESP_position[2] + 0.8]) cube([120, 90, 0.1], center = true);
}
module Box() {
  hull() for (i = [-1, 1]) {
    translate([0, 0, i*9  - (i+1)/2])  linear_extrude(1) MidPolygon();
    translate([0, 0, i*18 - (i+1)/2])  linear_extrude(1) SidePolygon();
  }
}
// ============================================================
// LITECASELIDAR ELECTRONICS
// ============================================================
module ESP() {
  difference() {
    color("black") translate([24.6, 0, 0.2]) cube(Lite_ESP_dimensions, center = true);
    for (i = [-1, 1]) for (j = [-1, 1])
      translate([i*24.6 + 22.6, j*12.5 - 2.5, -4.7]) cube([4, 5, 5]);
  }
}
module USB_hole() {
  translate(Lite_USB) {
    translate([0, 0, -2.25]) rounded_cube(45, 12.5, 8, 0, 0, center = true);
    rounded_cube(45, 10, 20, 2.5, 0, center = true);
  }
}
module UltrasonicCarrier(i, h = 30) {
  translate([0, 0, -h/2 + 34/2]) {
    color("blue") translate([23.9, i*7.3, 17.99]) cube([42.5, 1.4, h], center = true);
    hull() {
      translate([Lite_transducer_position[0], 0, 14.99]) cube([42.5, 21.5, h], center = true);
      translate([Lite_transducer_position[0], 0, 16.99]) cube([42.5, 16.5, h], center = true);
      translate([Lite_transducer_position[0], 0, 10.99]) cube([49.5, 18.5, h], center = true);
    }
    intersection() {
      translate([0, 0, +h/2 - 34/2])
        hull() {
          translate(Lite_transducer_position - [0, 8*i, 100]) rotate([i*90, 0, 0])
            cylinder(d1 = Lite_transducer_diameter + 12, d2 = Lite_transducer_diameter, h = 8.5);
          translate(Lite_transducer_position - [0, 8*i, 0]) rotate([i*90, 0, 0])
            cylinder(d1 = Lite_transducer_diameter + 12, d2 = Lite_transducer_diameter, h = 8.5);
        }
      color("blue") translate([23.9, i*7, 17.99]) cube([41.5, 60, h + 14], center = true);
    }
  }
}
module Screwbump(size = 6, hole_diameter = 3.8, height = 6, bottom = true, toppart = 2.1, insert = 4) {
  outer_polygon = [[size,0,0], [-size,0,0], [-size,size,size], [0,3*size,size], [size,size,size]];
  difference() {
    hull() {
      translate([0,0,0])        polyRoundExtrude(outer_polygon, 1, 0, 0);
      translate([0,0,height-1]) polyRoundExtrude(outer_polygon, 1, 0, 0);
      if (bottom) translate([0,-0.01,1.3*height]) rotate([90,0,0]) cylinder(d = size, h = 0.1);
    }
    translate([0, size, toppart])  cylinder(d = insert, h = height - toppart);
    translate([0, size, -0.01])    cylinder(d = hole_diameter, h = toppart);
  }
}
// ============================================================
// TF-LUNA
// ============================================================
module _tfluna_import(cutter=false) {
  s = cutter ? [tfluna_cutter_scale_up, tfluna_cutter_scale_up, tfluna_cutter_scale_up] : [1,1,1];
  scale(tfluna_scale) scale(s) import(tfluna_file, convexity = 10);
}
module TFLuna_at_old_tube_pos(i, cutter=false) {
  local_off = (i < 0) ? tfluna_pos_offset_m : tfluna_pos_offset_p;
  pos = Lite_transducer_position - [0, 8*i, 0] + local_off;
  translate(pos)
    rotate(tfluna_rot_common)
      if (i > 0) mirror(tfluna_mirror_axis) _tfluna_import(cutter=cutter);
      else       _tfluna_import(cutter=cutter);
}
module TFLuna_pair(cutter=false) {
  for (i = [-1, 1]) {
    if (cutter) render() TFLuna_at_old_tube_pos(i, cutter=true);
    else        TFLuna_at_old_tube_pos(i, cutter=false);
  }
}
// ============================================================
// THROUGH-BOHRUNGEN (OVAL)
// ============================================================
module ThroughOval() {
  base = through_base_pos + through_offset;
  d = through_d + 2*through_clearance;
  L = through_oval_length + 2*through_clearance;
  half = (L - d) / 2;
  function vnorm(v) = v / max(norm(v), 1e-9);
  v = vnorm(through_sep_vec) * half;
  module oriented_cyl(pos) {
    if (through_axis == "x")
      translate(pos) rotate([0, 90, 0]) cylinder(d=d, h=through_h, center=true);
    else if (through_axis == "y")
      translate(pos) rotate([90, 0, 0]) cylinder(d=d, h=through_h, center=true);
    else
      translate(pos) cylinder(d=d, h=through_h, center=true);
  }
  hull() {
    oriented_cyl(base + v);
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

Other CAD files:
src/LiteCaseLidar/18650_BatteryShield_with_StandardMount.scad
src/LiteCaseLidar/HandlebarButton.scad
src/LiteCaseLidar/LiteCase_lidar.scad
src/LiteCaseLidar/SeatPostMount_long.scad
src/LiteCaseLidar/Spacer.scad
src/Mounting/SeatPostMount_long_bat.scad

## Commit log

2026-01-06 Add LiteCaseLidar
    [HandlebarButton.scad, LiteCase_lidar.scad, Spacer.scad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]
2026-01-17 Anpassungen an Schale, Oval statt zwei Röhren
    [LiteCase_lidar.scad, LiteCase_lidar_Schale.stl]
2026-02-12 Add battery shield cases and extended seat post mounts
    [18650 Battery Shield V3 Case top.stl, 18650 Battery Shield V3 Case.scad, 18650 Battery Shield V3 Case_bottom.stl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]
2026-02-19 fehlerhafte files gelöscht
    [18650 Battery Shield V3 Case top.stl, 18650 Battery Shield V3 Case.scad, 18650 Battery Shield V3 Case_bottom.stl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]
2026-02-27 Add SPDX license headers to LiteCaseLidar scad files
    [18650 Battery Shield V3 Case.scad, 18650_BatteryShield_with_LiteCase_lidar_Deckel.scad, 18650_BatteryShield_with_StandardMount.scad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]
